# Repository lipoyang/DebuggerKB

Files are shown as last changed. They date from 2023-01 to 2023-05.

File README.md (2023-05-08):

DebuggerKB
=========
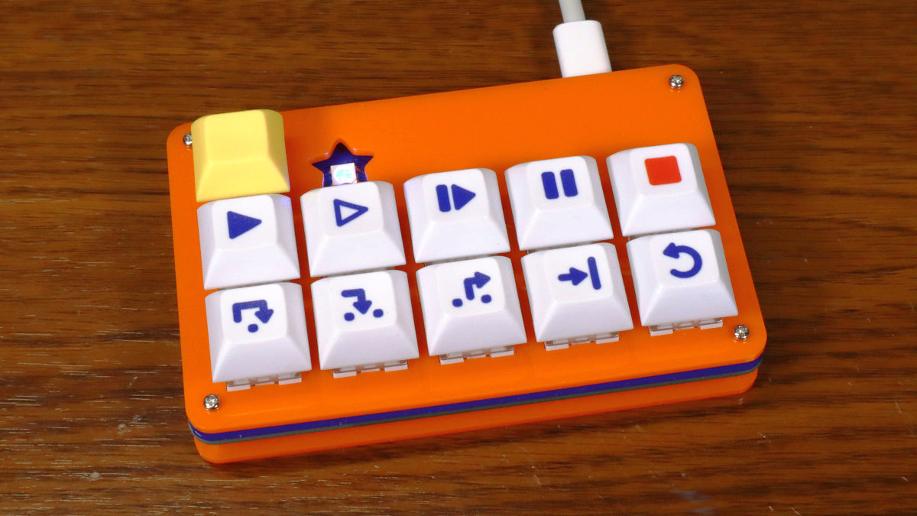
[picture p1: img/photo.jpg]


## 概要
IDEでのデバッグ関連のショートカットキーを並べた専用キーボードです。

* 有線接続(USB HID)と無線接続(BLE HID)の両方に対応。
* LiPoバッテリー(400mAh)と充電回路を内蔵。
* キーマップは最大8レイヤーまで登録でき、切替キーでレイヤーを切り替え可能。
* キーマップはUSB接続時にWebアプリから設定可能。<br>(PC版の Chrome や Edge など Web Serial API に対応したブラウザが必要)
* Nordic nRF52840 搭載。 (Seeed Studio XIAO nRF52840)
* Arduinoベースの独自ファームウェア。 (QMKではありません。)

## キーマップの設定
[Webアプリ](app/DebuggerKB_Config/)から、各レイヤーの名称、LED表示色、キーマップを設定できます。

キーボードをUSB接続すると、HIDと仮想COMポートの複合デバイスになるので、Webアプリから仮想COMポートを選択して接続します。

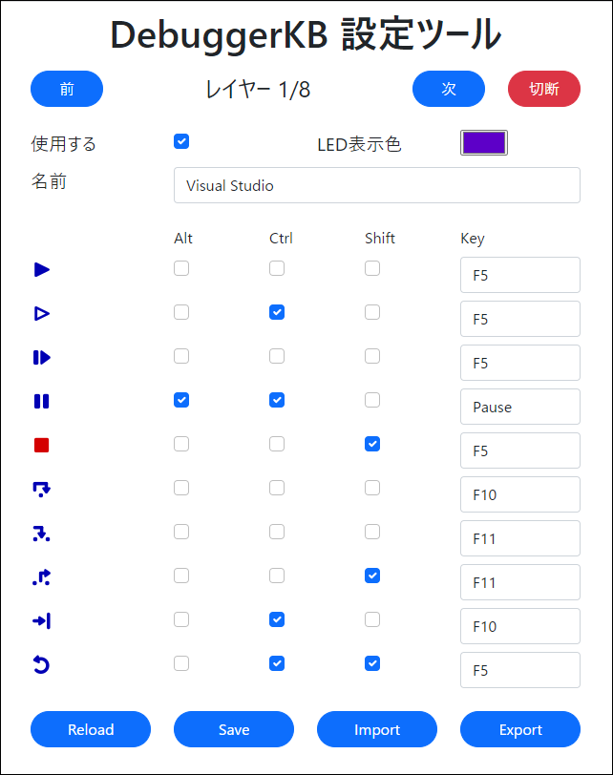
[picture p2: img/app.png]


## デフォルトのキーマップ
初期状態では4つのレイヤーが登録されています。

| キー | 機能名 (例) |Visual Studio | Eclipse | Android Studio | MPLAB X |
| ---- | ---- | ---- | ---- | ---- |---- |
|  | Debug | F5 | F11 | Shift+F9  | 割当なし |
|  | Run | Ctrl+F5 | Ctrl+F11 | Shift+F10 | 割当なし |
|  | Continue | F5 | F8 | F9 | F5 |
|  | Pause | Ctrl+Alt+Pause| 割当なし  | 割当なし  | Ctrl+Alt+8 |
|  | Stop | Shift+F5 | Ctrl+F2  | Ctrl+F2 | Shift+F5 |
|  | Step Over | F10 | F6 | F8 | F8 |
|  | Step Into | F11 | F5 | F7 | F7 |
|   | Steo Out | Shift+F11 | F7 | Shift+F8  | Ctrl+F7 |
|  | Run To Cursol| Ctrl+F10 | Ctrl+R | Alt+F9 | F4 |
|   | Restart | Ctrl+Shift+F5 | 割当なし  | 割当なし  | 割当なし |

※ 機能名はIDEによって異同があります。詳しくは[こちら](FunctionName.xlsx)。  
※ Pauseキー = Breakキー 

 と  を同時に押しながらUSBケーブルを接続するとキーマップがデフォルト設定に初期化されます。

## キースイッチとキーキャップについて
* キースイッチは Cherry MX スイッチ互換の Keilh BOX スイッチを使用しました。
* デバッガの操作という用途を考慮し、軸種はクリック感のある茶軸を選びました。
* [Kailh Switch Socket](https://shop.yushakobo.jp/products/a01ps) を使用しており、キースイッチの着脱が可能です。
* パターン設計の都合で、キースイッチの向きは North Facing (LED穴が上側) にしました。
* キーキャップは、DSAプロファイルのものを使用しました。
* キーキャップの印字は、[遊舎工房](https://yushakobo.jp/)さんのキーキャップUVプリントサービスを利用しました。
* キーキャップの印字データは、白キーキャップを前提として作成しました。(下地の白インクのデータ無し)

## 筐体について
* ボトムプレートとトッププレートは厚さ2mmのアクリル板(キャスト材)を使用しました。
* アクリル板の加工は、[工房Emerge+](https://www.emergeplus.jp/)さんのレーザー加工サービスを利用しました。
* 四隅の穴はM2ネジ用です。

## プリント基板について
* 基板製造は[PCBGOGO](https://www.pcbgogo.jp/)さんのサービスを利用しました。
* 厚さ1.6mmの両面基板で製造しました。
* 実装は手ハンダです。Seeed XIAO nRF52840 の裏面パッドはスルーホールからハンダ付けしました。

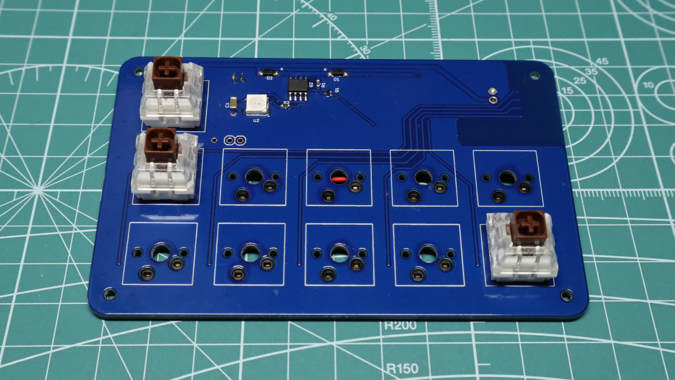
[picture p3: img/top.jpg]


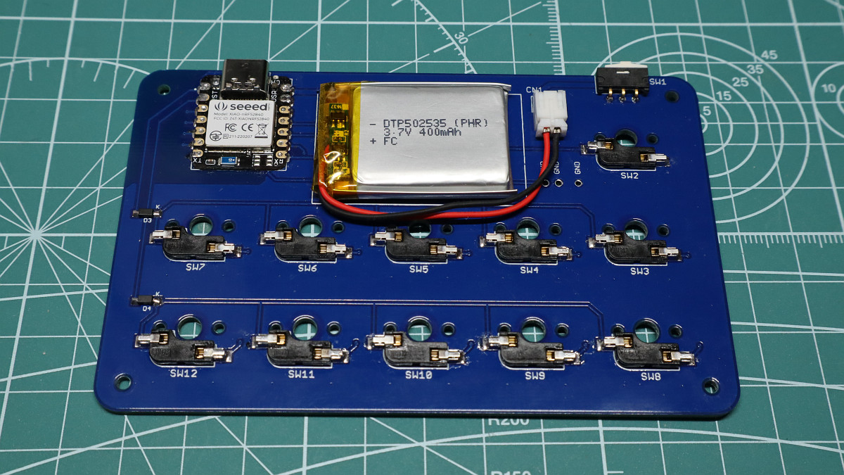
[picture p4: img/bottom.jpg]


## ファームウェアについて

* ファームウェアは Arduinoベースで作成しました。
* Arduino IDEの「ファイル」＞「環境設定」＞「追加のボードマネージャのURL」に下記URLを追加します。
```
https://files.seeedstudio.com/arduino/package_seeeduino_boards_index.json
```
* 「ツール」＞「ボード」＞「ボードマネージャ」で「Seeed nRF52 Boards」をインストールします。
* 「ツール」＞「ボード」で Seeed nRF52 Boards > Seeed XIAO nRF52840 を選択します。
* Seeed nRF52 mbed-enabled Boards ではないことに注意してください。
* シリアルポートが認識しないときは、USBコネクタの横の小さなリセットボタン(RSTのシルクあり)をダブルクリックしてください。

## 依存ライブラリ
<table>
<tr><td>Adafruit NeoPixel </td><td>要インストール</td></tr>
<tr><td>Adafruit TinyUSB  </td><td>Seeed nRF52 Boards に付属</td></tr>
<tr><td>Adafruit_LittleFS </td><td>Seeed nRF52 Boards に付属</td></tr>
<tr><td>InternalFileSystem</td><td>Seeed nRF52 Boards に付属</td></tr>
<tr><td>Bluefruit         </td><td>Seeed nRF52 Boards に付属</td></tr>
</table>

## ファイル一覧

* hard/
    * DebuggerKB.sch/brd : 回路/基板設計データ(Eagle形式)
    * DebuggerKB.pdf : 回路図(PDF)
    * DebuggerKB.zip : ガーバーデータの圧縮ファイル
    * DebuggerKB_BOM.xlsx : BOMリスト(Excel形式)
* mecha/
    * A5_DebuggerKB.svg : プレート(アクリル板)の加工データ
    * DSA_1u_4x4_DebuggerKB.svg : キーキャップのUV印刷データ
* firm/DebuggerKB/
    * DebuggerKB.ino : キーボードのファームウェア (Arduinoスケッチ)
    * \*.h, \*.cpp: ファームウェアで使用する各種クラス宣言と実装
* app/DebuggerKB_Config/ 
    * index.html : キーマップ設定アプリ (webアプリ)
    * \*.js, \*.png, css/\*, lib/\* : キーマップ設定アプリで使用する各種ファイル

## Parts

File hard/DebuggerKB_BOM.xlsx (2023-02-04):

No | Reference | Part Number | Vender | Description | DNP | Qty | Unit Price | Price | Lot Size | Supplier | Supplier Code
1 | C1 | 100u(3216) | (generic) | 3216型 |  | 1 | 20 | 20 | 10 | 秋月 | P-15633
2 | CN1 | S2B-PH-K-S | JST | PH 2極 L型ポスト |  | 1 | 16 | 16 | 1 | 共立 | N1BSGU
3 | D1,2 | SS2040FL | PANJIT | ショットキーバリアダイオード 40V2A |  | 2 | 15 | 30 | 20 | 秋月 | I-02073
4 | D3,4 | 1N4148W | Diodes Inc. | 小信号用汎用ダイオード |  | 2 | 3.75 | 7.5 | 40 | 秋月 | I-07084
5 | Q1 | DTC014EEB | ROHM | NPNデジタルトランジスタ |  | 1 | 3.2 | 3.2 | 200 | RS | 124-6536
6 | Q2 | TPC8125 | Toshiba | PMOS FET |  | 1 | 36.8 | 36.8 | 5 | RS | 756-3817
7 | R1 | 10k(1608) | (generic) | 1608型 |  | 1 | 0.2 | 0.2 | 2500 | 秋月 | R-06103
8 | R2 | 470(1608) | (generic) | 1608型 |  | 1 | 0.2 | 0.2 | 2500 | 秋月 | R-06471
9 | SW1 | CL-SA-12C-02 | コパル電子 | 横型スライドスイッチ |  | 1 | 167 | 167 | 1 | マルツ | -
10 | SW1 代替 | ESP2020 | 台湾製 | 横型スライドスイッチ | 代替品 | 0 | 88 | 0 | 0 | 共立 | C5U122
11 | SW2-12 | CPG151101S11-16 | Kailh | MX用スイッチソケット |  | 11 | 18.7 | 205.7 | 10 | 遊舎工房 | A0500PS-MX-10
12 | U1 | XIAO nRF52840 | Seeed | BLEマイコンモジュール |  | 1 | 1936 | 1936 | 1 | スイッチ | SEEED-102010448
13 | U2 | WS2812B | Worldsemi | NeoPixcel フルカラーシリアルLED |  | 1 | 25 | 25 | 2 | 秋月 | I-07915
14 | - | - | PCBGOGO | 基板 |  | 1 | 668.7 | 668.7 | 10 | PCBGOGO | -
 |  |  |  |  |  |  | Total | 3116.3

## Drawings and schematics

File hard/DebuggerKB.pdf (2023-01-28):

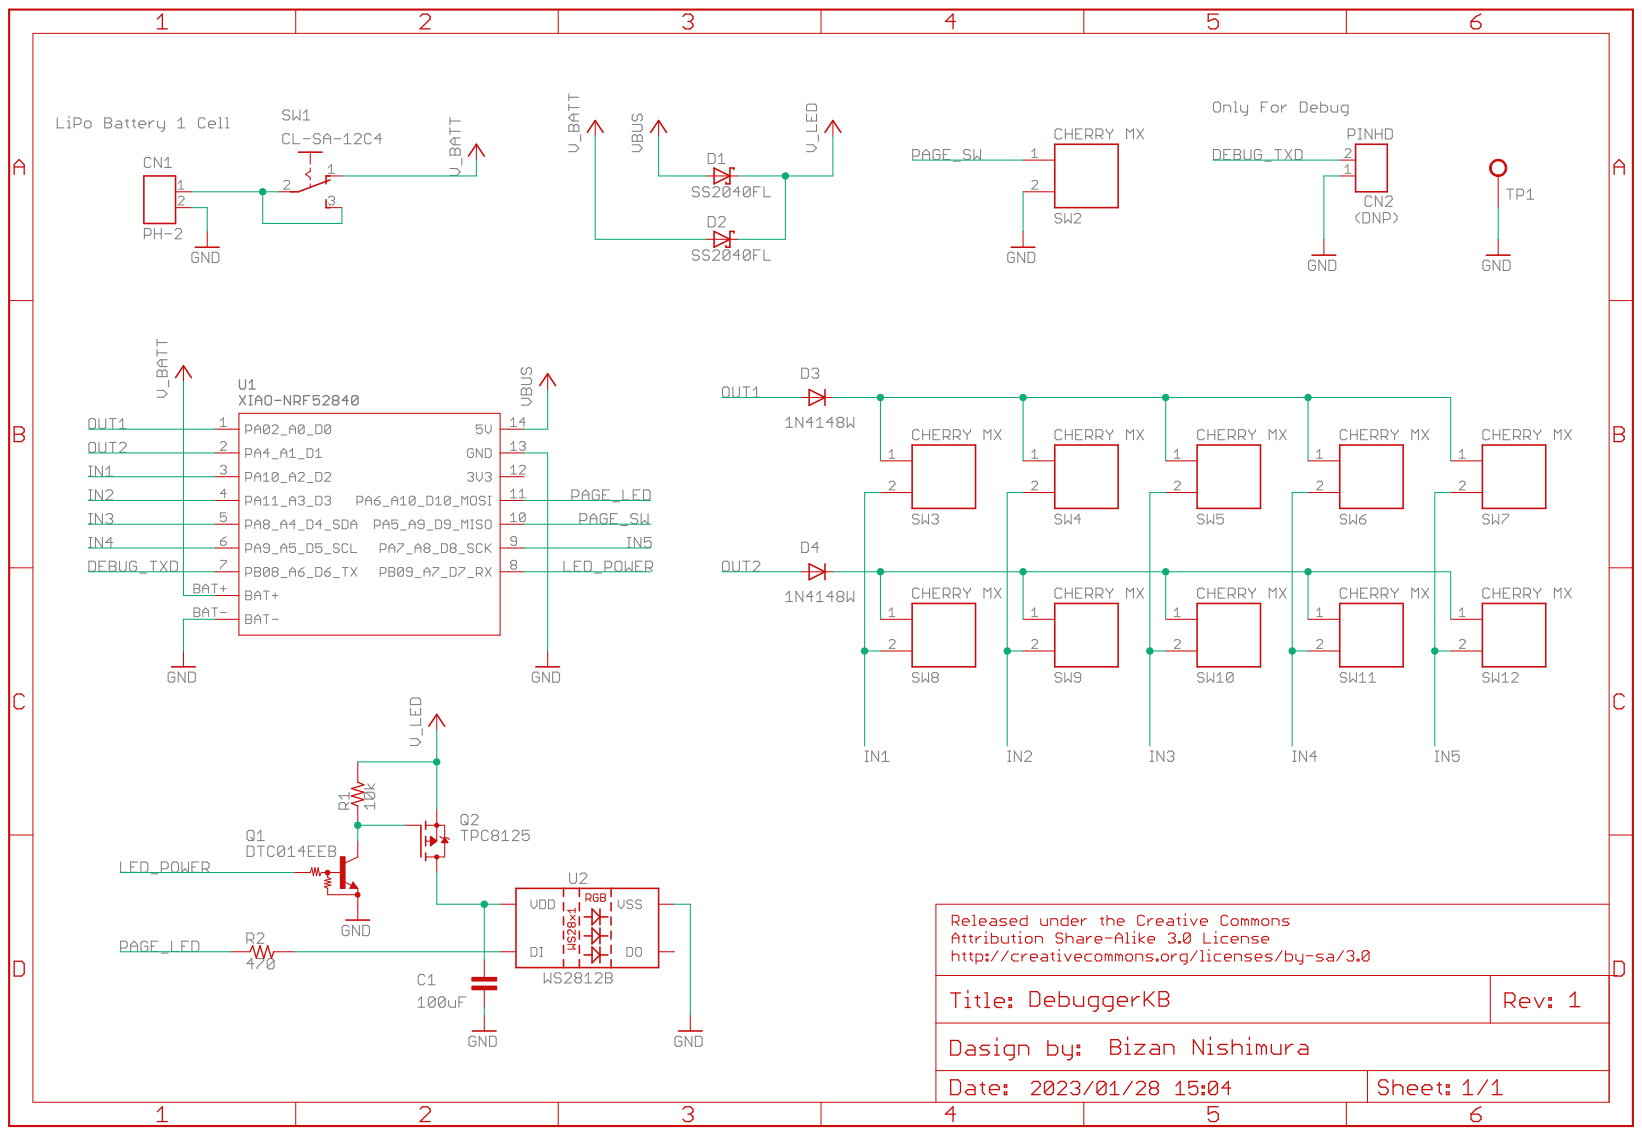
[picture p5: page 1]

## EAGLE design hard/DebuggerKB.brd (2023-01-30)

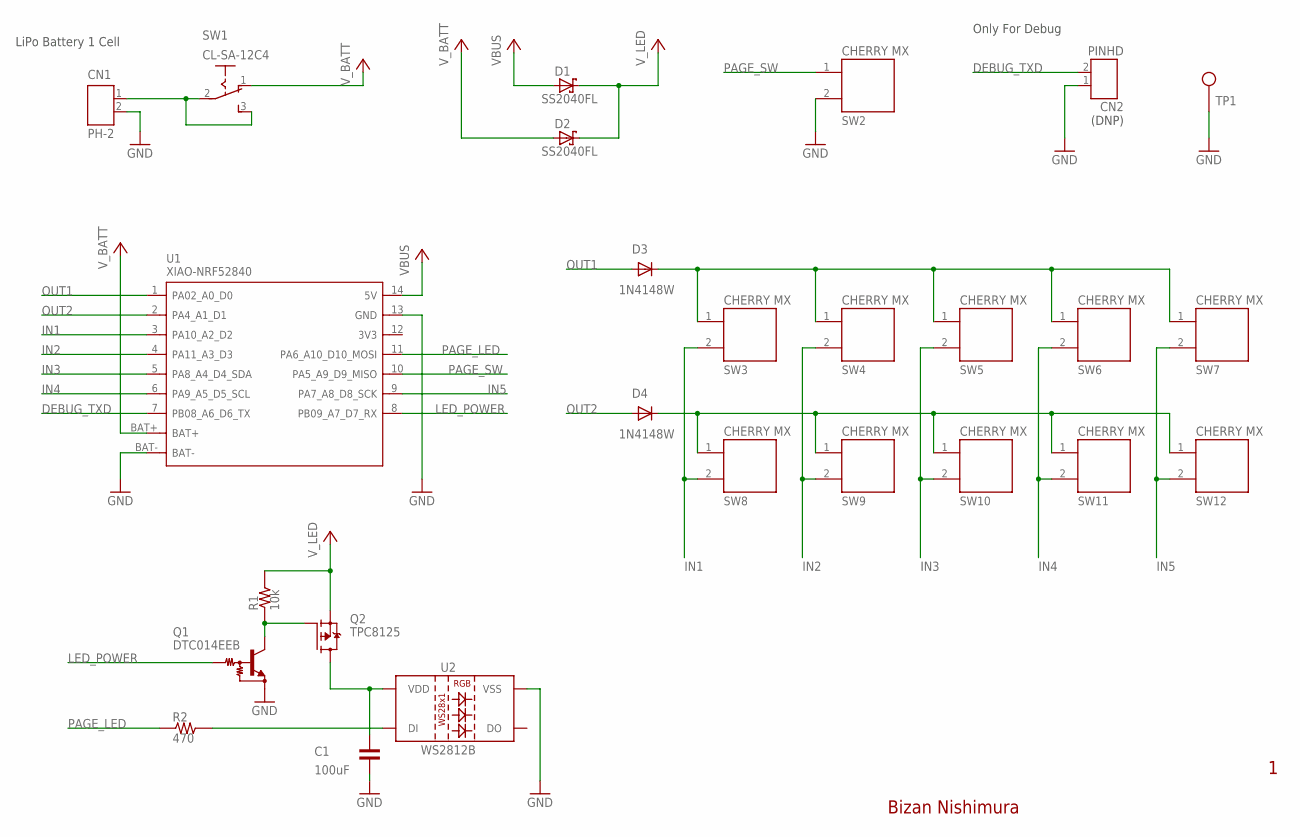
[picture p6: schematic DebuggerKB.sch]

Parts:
C1: 100uF; CP3216
CN1: PH-2
CN2: PINHD; 1X02
D1, D2: SS2040FL; SOD123
D3, D4: 1N4148W; SOD123
Q1: DTC014EEB; SOT490
Q2: TPC8125; SO-8
R1: 10k; CP1608
R2: 470; CP1608
SW1: CL-SA-12C4
SW2, SW3, SW4, SW5, SW6, SW7, SW8, SW9, SW10, SW11, SW12: KAILH_SWITCH_SOCKET; SWITCH_SOCKET
TP1: TEST_PIN
U1: XIAO-NRF52840; XIAO-NRF52840-BAT
U2: WS2812B

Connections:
DEBUG_TXD: CN2.2, U1.7 (PB08_A6_D6_TX)
GND: C1.SMD2 (PIN2), CN1.2, CN2.1, Q1.2 (E), SW2.2 (PIN-2), TP1.1, U1.13 (GND), U1.BAT-, U2.3 (VSS)
IN1: SW3.2 (PIN-2), SW8.2 (PIN-2), U1.3 (PA10_A2_D2)
IN2: SW4.2 (PIN-2), SW9.2 (PIN-2), U1.4 (PA11_A3_D3)
IN3: SW5.2 (PIN-2), SW10.2 (PIN-2), U1.5 (PA8_A4_D4_SDA)
IN4: SW6.2 (PIN-2), SW11.2 (PIN-2), U1.6 (PA9_A5_D5_SCL)
IN5: SW7.2 (PIN-2), SW12.2 (PIN-2), U1.9 (PA7_A8_D8_SCK)
LED_POWER: Q1.1 (B), U1.8 (PB09_A7_D7_RX)
unnamed: C1.SMD1 (PIN1), Q2.5 (D), Q2.6 (D), Q2.7 (D), Q2.8 (D), U2.1 (VDD)
unnamed: CN1.1, SW1.2, SW1.3 (S)
unnamed: Q1.3 (C), Q2.4 (G), R1.SMD1 (PIN1)
unnamed: R2.SMD2 (PIN2), U2.4 (DI)
unnamed: D3.C, SW3.1 (PIN-1), SW4.1 (PIN-1), SW5.1 (PIN-1), SW6.1 (PIN-1), SW7.1 (PIN-1)
unnamed: D4.C, SW8.1 (PIN-1), SW9.1 (PIN-1), SW10.1 (PIN-1), SW11.1 (PIN-1), SW12.1 (PIN-1)
OUT1: D3.A, U1.1 (PA02_A0_D0)
OUT2: D4.A, U1.2 (PA4_A1_D1)
PAGE_LED: R2.SMD1 (PIN1), U1.11 (PA6_A10_D10_MOSI)
PAGE_SW: SW2.1 (PIN-1), U1.10 (PA5_A9_D9_MISO)
VBUS: D1.A, U1.14 (5V)
V_BATT: D2.A, SW1.1 (O), U1.BAT+
V_LED: D1.C, D2.C, Q2.1 (S), Q2.2 (S), Q2.3 (S), R1.SMD2 (PIN2)

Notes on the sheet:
Bizan Nishimura
LiPo Battery 1 Cell
(DNP)
Only For Debug

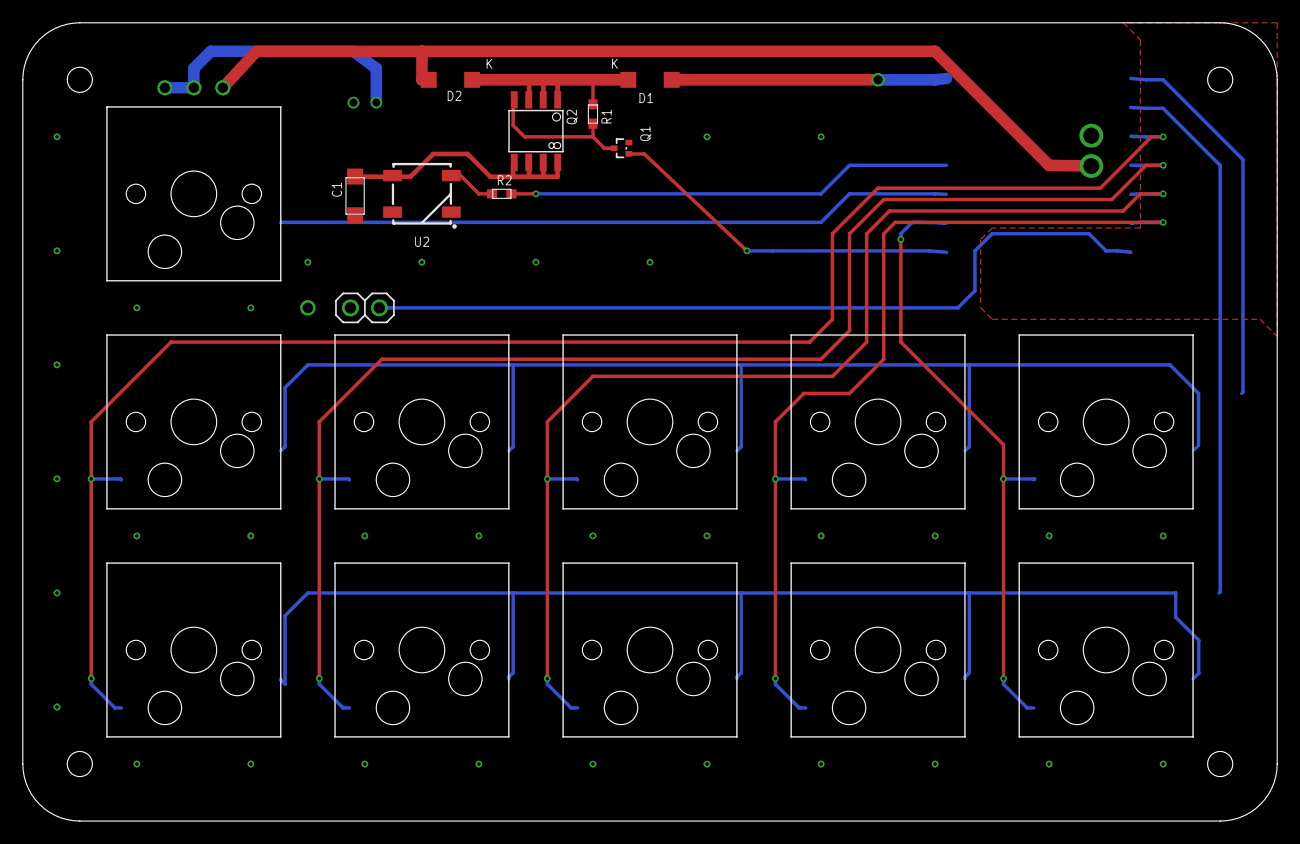
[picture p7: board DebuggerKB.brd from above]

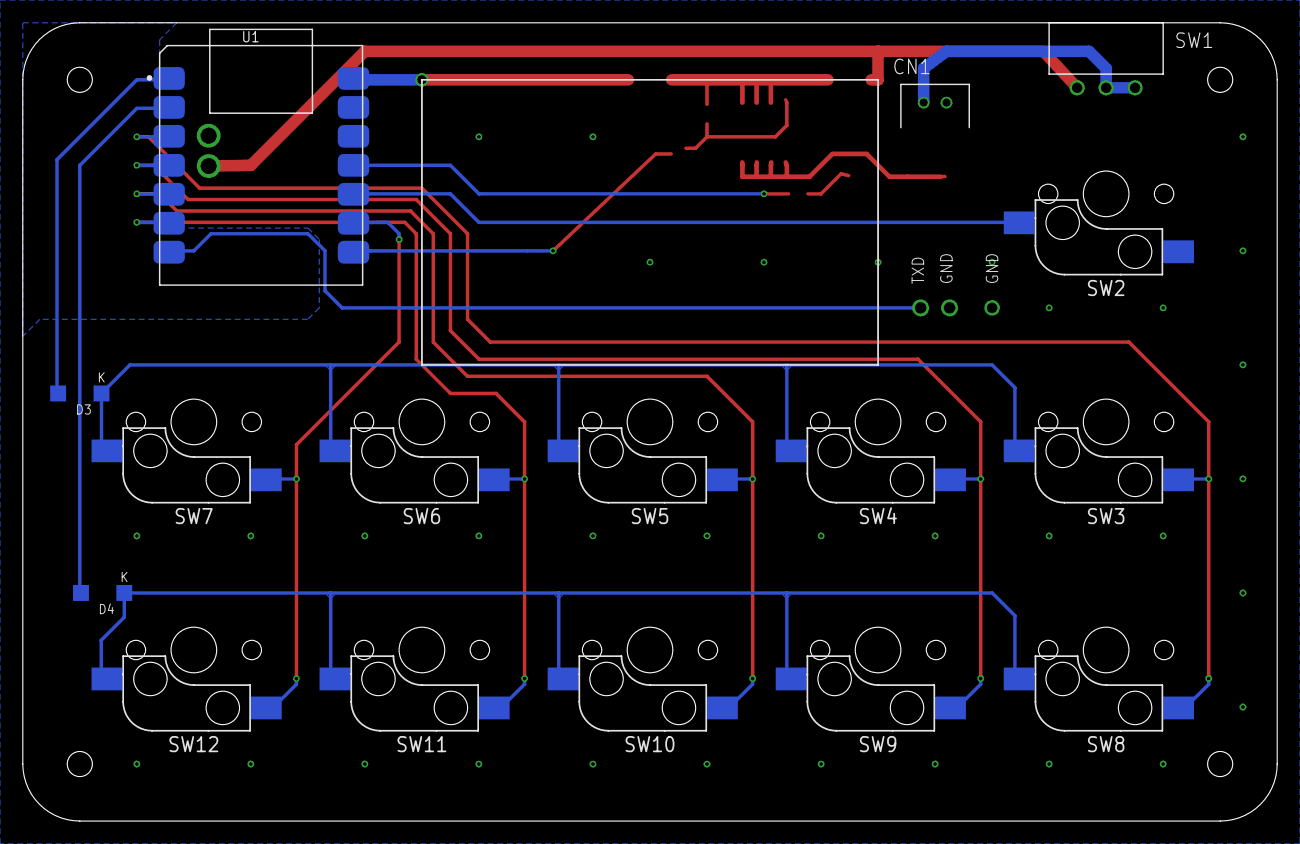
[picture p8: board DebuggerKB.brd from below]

Board: 2 copper layers, 110.0 x 70.0 mm, 26 parts (6 on the bottom side), 21 nets.

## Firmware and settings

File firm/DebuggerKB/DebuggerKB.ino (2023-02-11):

#include <Adafruit_TinyUSB.h>
#include <Adafruit_NeoPixel.h>
#include "UsbKeyboard.h"
#include "BleKeyboard.h"
#include "SerialCommand.h"
#include "KeyMatrix.h"
#include "Power.h"
#include "Switch.h"
#include "ColorLed.h"
#include "PollingTimer.h"

#define PIN_PAGE_SW      9  // Layer Swith pin
#define PIN_LED_POWER    7  // LED Power ON pin
#define PIN_PAGE_LED    10  // LED pin

#define KEY_INTERVAL     5  // Key Interval [msec]

// Layer Switch
Switch layerSwitch;
// Layer LED
ColorLed layerLed(PIN_PAGE_LED);
// Power Controller
Power power;

// USB Keyboard
UsbKeyboard usbKeyboard;
// BLE Keyboard
BleKeyboard bleKeyboard;
// USB or BLE Keyboard
Keyboard *keyboard;

// Key Matrix
KeyMatrix keyMatrix;
// Serial Command
SerialCommand serialCommand;
// Keymap Storage
KeyMapStorage keyMapStorage;

// Output Pins (for Key Matrix)
int outPin[ROW_NUM] = { 0, 1 };
// Input Pins  (for Key Matrix)
int inPin [COL_NUM] = { 2, 3, 4, 5, 8 };
// Keycode 
uint8_t keyTable[KEY_MAX][KEY_COMBI_MAX];

// is USB connected?
bool isUsbConnected;

// Interval Timer
IntervalTimer interval;

// Initialize
void setup()
{
    // Power
    power.begin(PIN_LED_POWER, PIN_PAGE_SW);
    
    // Layer Switch
    layerSwitch.begin(PIN_PAGE_SW);
    
    // Layer LED
    if (power.detectVbus()) {
        layerLed.begin(LED_BUS_POWERED);
    } else {
        layerLed.begin(LED_BAT_POWERED);
    }
    
    // begin Key Matrix
    keyMatrix.begin(outPin, inPin);
    
    // detect VBUS
    if (power.detectVbus()) {
        // USB Keyboard
        digitalWrite(LED_GREEN, LOW);
        keyboard = &usbKeyboard;
        isUsbConnected = true;
        
        // Factory Reset?
        if(keyMatrix.pressFactoryReset()){
            layerLed.setColor(COLOR_RED);
            delay(1000);
            keyMapStorage.factoryReset();
            layerLed.setColor(COLOR_GREEN);
            delay(3000);
            NVIC_SystemReset();
        }
        
    } else {
        // BLE Keyboard
        digitalWrite(LED_BLUE,  LOW);
        keyboard = &bleKeyboard;
        isUsbConnected = false;
    }

    // begin HID (USB of BLE)
    keyboard->begin();
    
    // begin Serial Command
    serialCommand.keyMaps = keyMapStorage.keyMaps;
    if(isUsbConnected) serialCommand.begin();
    
    // Keymap Strage
    keyMapStorage.begin();
    keyMapStorage.getKeyTable(keyTable);
    
    // set Keymap to Key Matrix
    keyMatrix.setKeyTable(keyTable);
    
    // show Layer LED
    layerLed.setColor(keyMapStorage.getLedColor());
    
    // begin Interval Timer
    interval.set(KEY_INTERVAL);
}

// Main Loop
void loop()
{
    // key interval
    if(!interval.elapsed()) return;

    // layer LED control
    layerLed.task();
    
    // check low battery voltage
    bool lowBattery = power.checkLowBattery();
    // check no operation
    bool noOperation = power.checkNoOperation();
    // sleep?
    if(lowBattery || noOperation){
        layerLed.turnOff();
        power.sleep();
    }
    
    // serial command task
    if(isUsbConnected){
        int ret = serialCommand.task();
        if(ret == RET_WRITE){
            keyMapStorage.save();
            keyMapStorage.changeLayer(false);
            keyMapStorage.getKeyTable(keyTable);
            keyMatrix.setKeyTable(keyTable);
            
            layerLed.setColor(keyMapStorage.getLedColor());
        }
    }
    
    // get layer switch event
    int event = layerSwitch.get();
    if(event == SW_EVENT_SHORT){
        keyMapStorage.changeLayer(true);
        keyMapStorage.getKeyTable(keyTable);
        keyMatrix.setKeyTable(keyTable);
        
        layerLed.setColor(keyMapStorage.getLedColor());
        power.kick();
    }
    else if(event == SW_EVENT_LONG){
        layerLed.turnOnWhile();
        power.kick();
    }

    // skip if hid is not ready
    if ( !keyboard->ready() ) return;

    // scan key matrix
    if(keyMatrix.scan()){
        // press any key?
        if(keyMatrix.pressAnyKey()){
            // wake up
            keyboard->wakeup();
            // get key code
            uint8_t keycode[KEY_CODE_MAX] = { 0 };
            keyMatrix.getKey(keycode);
            
            // keyboard report
            if(keycode[0] != 0){
                keyboard->keyboardReport(keycode);
                
                layerLed.turnOnMoment();
                power.kick();
            }
        }else{
            // key release
            keyboard->keyboardRelease();
        }
    }
}

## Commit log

2023-01-13 add Switch class
2023-01-14 add Power class
2023-01-14 add to Power class
2023-01-14 add to Power
2023-01-22 modify LED control
2023-01-22 modify LED and Switch control
2023-01-27 add board design
    [DebuggerKB.brd, DebuggerKB.sch]
2023-01-28 modify board design
    [DebuggerKB.brd, DebuggerKB.sch]
2023-01-30 add plate design
2023-02-04 add BOM
    [DebuggerKB_BOM.xlsx]
2023-02-11 add to README
    [FunctionName.xlsx]

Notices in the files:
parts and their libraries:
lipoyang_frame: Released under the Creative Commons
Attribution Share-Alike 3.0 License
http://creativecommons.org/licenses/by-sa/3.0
